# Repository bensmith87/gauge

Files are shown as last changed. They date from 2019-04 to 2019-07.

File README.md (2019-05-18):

<div>Icons made by <a href="https://www.freepik.com/" title="Freepik">Freepik</a> from <a href="https://www.flaticon.com/" 			    title="Flaticon">www.flaticon.com</a> is licensed by <a href="http://creativecommons.org/licenses/by/3.0/" 			    title="Creative Commons BY 3.0" target="_blank">CC 3.0 BY</a></div>

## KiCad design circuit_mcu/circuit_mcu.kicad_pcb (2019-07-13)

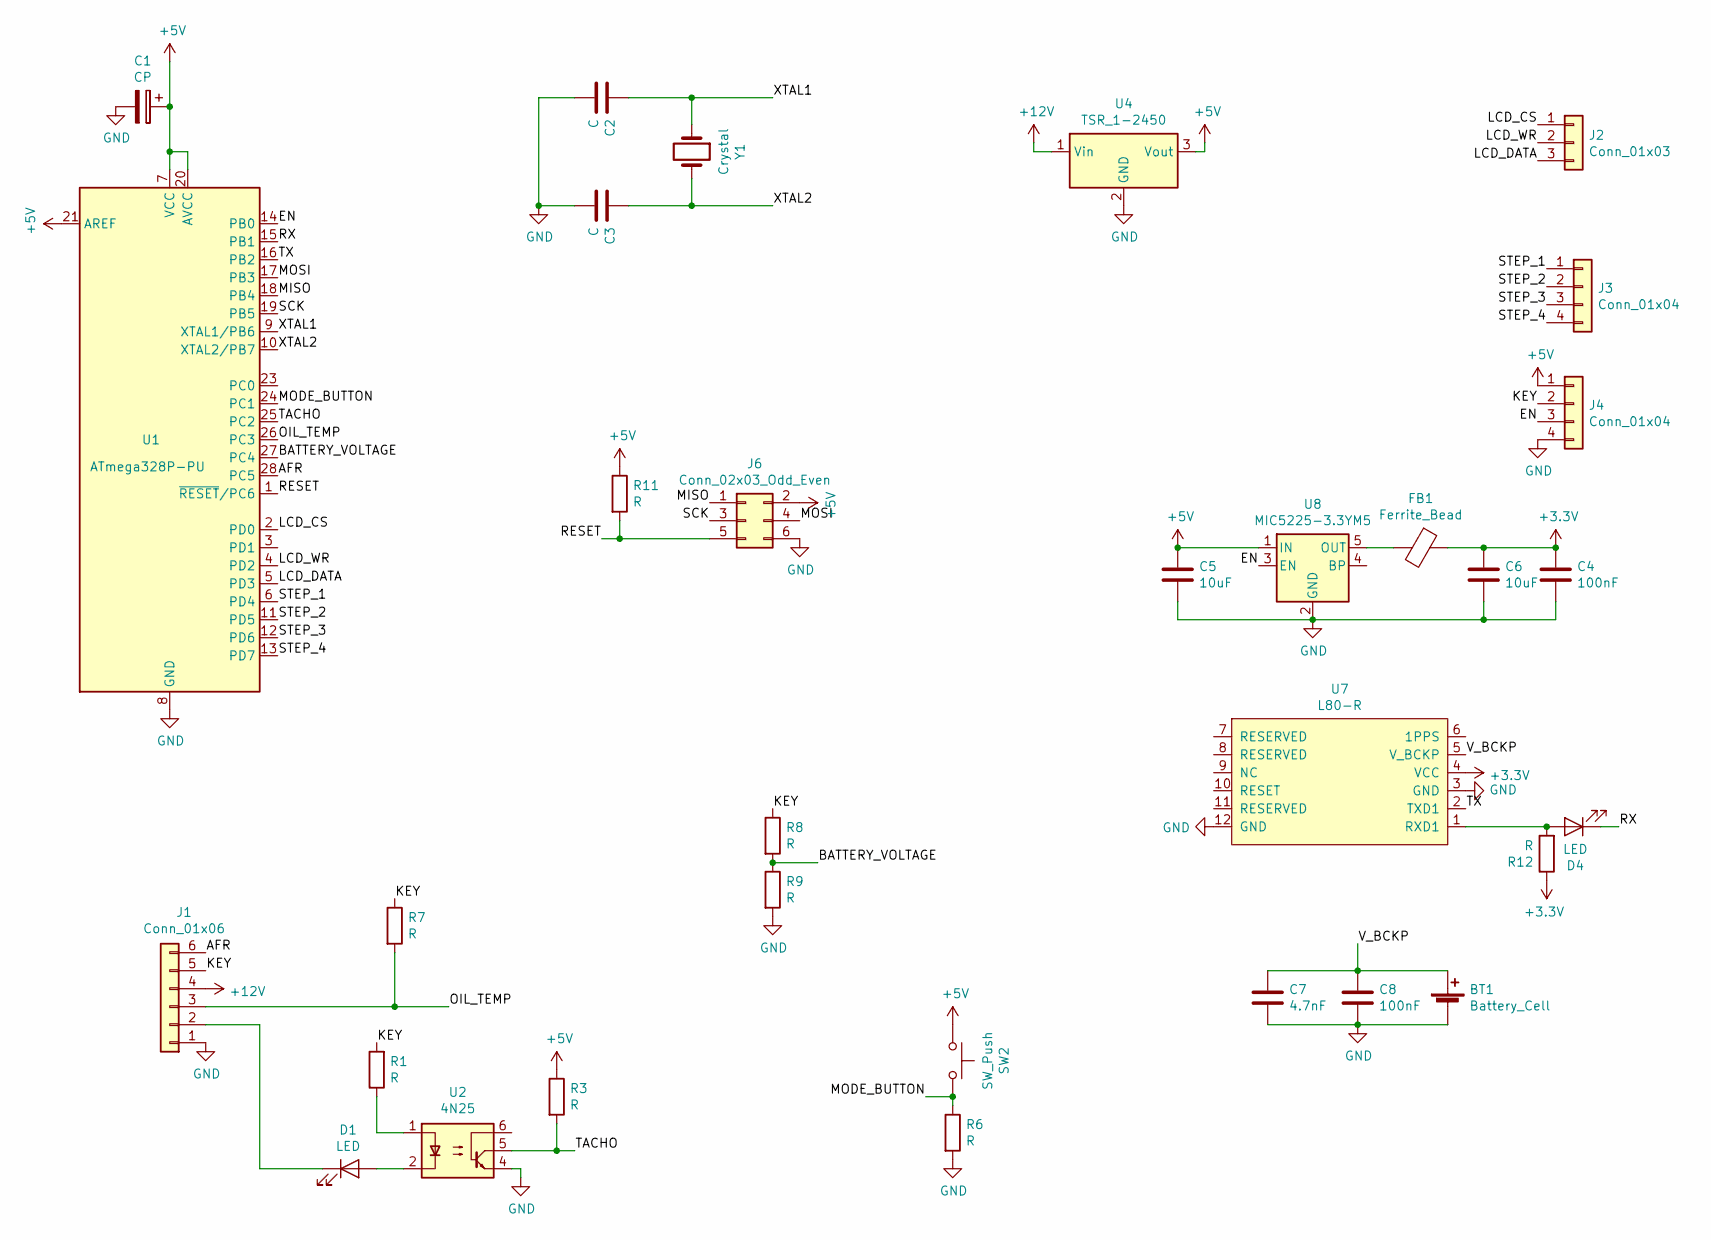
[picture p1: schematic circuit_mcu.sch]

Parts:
BT1: Battery_Cell; Coin Battery Holder
C1: CP; CP_Radial_D4.0mm_P1.50mm
C2, C3: C; C_1206_3216Metric
C4, C8: 100nF; C_1206_3216Metric
C5, C6: 10uF; C_1206_3216Metric
C7: 4.7nF; C_1206_3216Metric
D1, D4: LED; LED_1206_3216Metric
FB1: Ferrite_Bead; L_1206_3216Metric
J1: Conn_01x06; PinSocket_1x06_P2.54mm_Vertical
J2: Conn_01x03; PinSocket_1x03_P2.54mm_Vertical
J3, J4: Conn_01x04; PinSocket_1x04_P2.54mm_Vertical
J6: Conn_02x03_Odd_Even; PinHeader_2x03_P2.54mm_Vertical
R1, R3, R6, R7, R8, R9, R11, R12: R; R_1206_3216Metric
SW2: SW_Push; PinSocket_1x02_P2.54mm_Vertical
U1: ATmega328P-PU; DIP-28_W7.62mm
U2: 4N25; DIP-6_W7.62mm
U4: TSR_1-2450; Converter_DCDC_TRACO_TSR-1_THT
U7: L80-R
U8: MIC5225-3.3YM5; SOT-23-5
Y1: Crystal; Resonator-2Pin_W7.0mm_H2.5mm

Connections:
+3V3: C4.2, C6.2, FB1.1, R12.1, U7.4 (VCC)
+5V: C1.1, C5.2, J4.1, J6.2, R3.1, R11.1, SW2.1, U1.7 (VCC), U1.20 (AVCC), U1.21 (AREF), U4.3 (Vout), U8.1 (IN)
+12V: J1.4, U4.1 (Vin)
/AFR: J1.6, U1.28 (PC5)
/BATTERY_VOLTAGE: R8.2, R9.1, U1.27 (PC4)
/EN: J4.3, U1.14 (PB0), U8.3 (EN)
/KEY: J1.5, J4.2, R1.2, R7.1, R8.1
/LCD_CS: J2.1, U1.2 (PD0)
/LCD_DATA: J2.3, U1.5 (PD3)
/LCD_WR: J2.2, U1.4 (PD2)
/MISO: J6.1, U1.18 (PB4)
/MODE_BUTTON: R6.1, SW2.2, U1.24 (PC1)
/MOSI: J6.4, U1.17 (PB3)
/OIL_TEMP: J1.3, R7.2, U1.26 (PC3)
/RESET: J6.5, R11.2, U1.1 (~RESET~/PC6)
/RX: D4.1 (K), U1.15 (PB1)
/SCK: J6.3, U1.19 (PB5)
/STEP_1: J3.1, U1.6 (PD4)
/STEP_2: J3.2, U1.11 (PD5)
/STEP_3: J3.3, U1.12 (PD6)
/STEP_4: J3.4, U1.13 (PD7)
/TACHO: R3.2, U1.25 (PC2), U2.5
/TX: U1.16 (PB2), U7.2 (TXD1)
/V_BCKP: BT1.1 (+), C7.2, C8.2, U7.5 (V_BCKP)
/XTAL1: C2.1, U1.9 (XTAL1/PB6), Y1.1
/XTAL2: C3.1, U1.10 (XTAL2/PB7), Y1.2
GND: BT1.2 (-), C1.2, C2.2, C3.2, C4.1, C5.1, C6.1, C7.1, C8.1, J1.1, J4.4, J6.6, R6.2, R9.2, U1.8 (GND), U1.22 (GND), U2.4, U4.2 (GND), U7.3 (GND), U7.12 (GND), U8.2 (GND)
unnamed: D1.1 (K), J1.2
unnamed: D1.2 (A), U2.2
unnamed: D4.2 (A), R12.2, U7.1 (RXD1)
unnamed: FB1.2, U8.5 (OUT)
unnamed: R1.1, U2.1

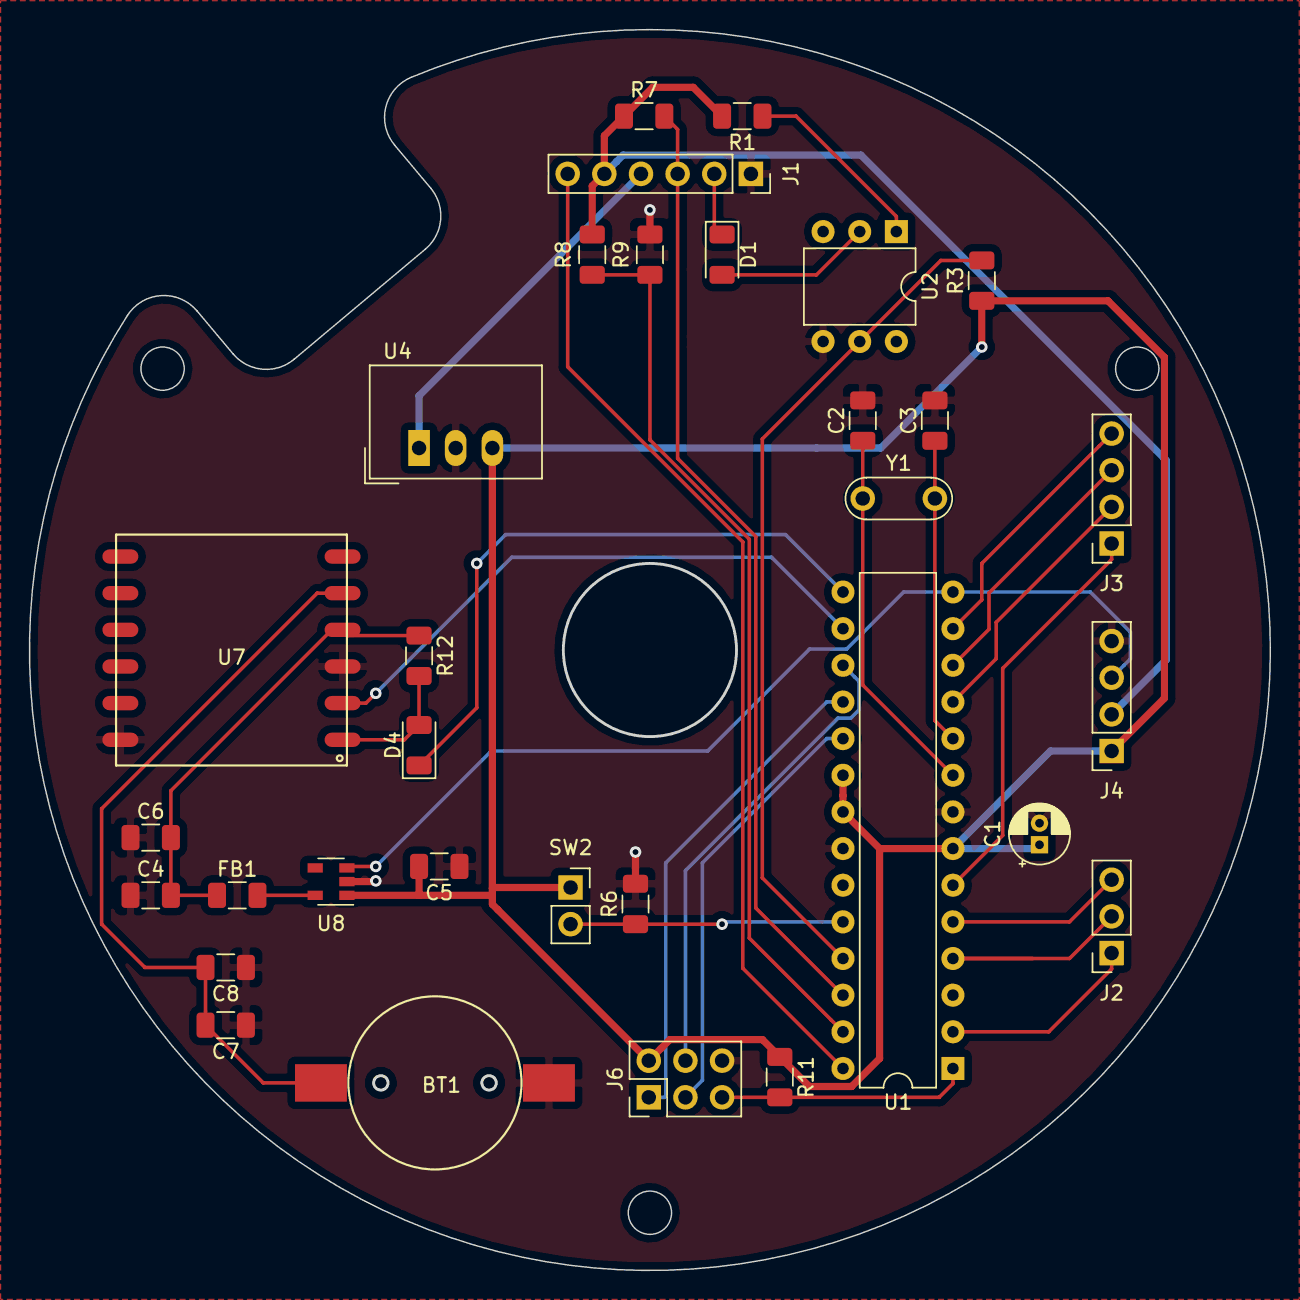
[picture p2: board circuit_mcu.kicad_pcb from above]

Board: 2 copper layers, 86.0 x 86.0 mm, 32 parts (0 on the bottom side), 32 nets.

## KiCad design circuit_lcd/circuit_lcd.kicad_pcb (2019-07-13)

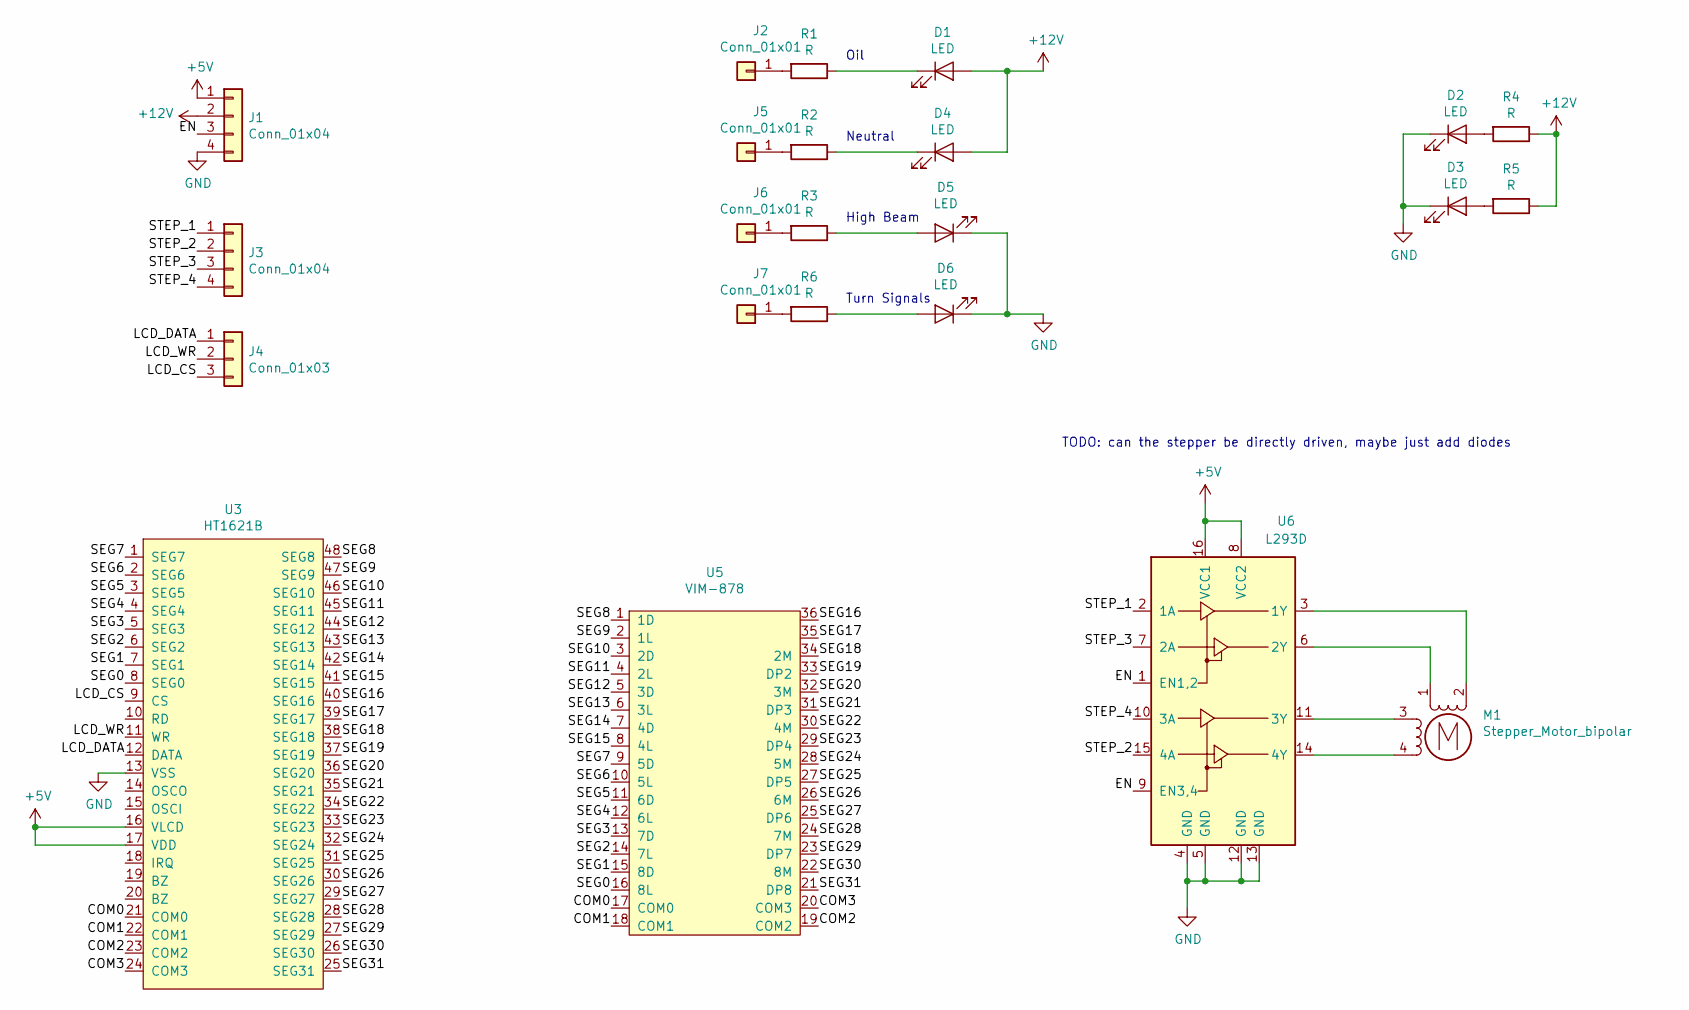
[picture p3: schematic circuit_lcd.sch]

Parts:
D1, D4, D5, D6: LED; LED_D5.0mm
D2, D3: LED; LED_1206_3216Metric
J1, J3: Conn_01x04; PinSocket_1x04_P2.54mm_Vertical
J2, J5, J6, J7: Conn_01x01; PinSocket_1x01_P2.54mm_Vertical
J4: Conn_01x03; PinSocket_1x03_P2.54mm_Vertical
M1: Stepper_Motor_bipolar; Stepper Motor
R1, R2, R3, R4, R5, R6: R; R_1206_3216Metric
U3: HT1621B; HT1621
U5: VIM-878; VIM-878-DP
U6: L293D; DIP-16_W7.62mm

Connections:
+5V: J1.1, U3.16 (VLCD), U3.17 (VDD), U6.8 (VCC2), U6.16 (VCC1)
+12V: D1.2 (A), D4.2 (A), J1.2, R4.1, R5.1
/COM0: U3.21 (COM0), U5.17 (COM0)
/COM1: U3.22 (COM1), U5.18 (COM1)
/COM2: U3.23 (COM2), U5.19 (COM2)
/COM3: U3.24 (COM3), U5.20 (COM3)
/EN: J1.3, U6.1 (EN1,2), U6.9 (EN3,4)
/LCD_CS: J4.3, U3.9 (CS)
/LCD_DATA: J4.1, U3.12 (DATA)
/LCD_WR: J4.2, U3.11 (WR)
/SEG0: U3.8 (SEG0), U5.16 (8L)
/SEG1: U3.7 (SEG1), U5.15 (8D)
/SEG2: U3.6 (SEG2), U5.14 (7L)
/SEG3: U3.5 (SEG3), U5.13 (7D)
/SEG4: U3.4 (SEG4), U5.12 (6L)
/SEG5: U3.3 (SEG5), U5.11 (6D)
/SEG6: U3.2 (SEG6), U5.10 (5L)
/SEG7: U3.1 (SEG7), U5.9 (5D)
/SEG8: U3.48 (SEG8), U5.1 (1D)
/SEG9: U3.47 (SEG9), U5.2 (1L)
/SEG10: U3.46 (SEG10), U5.3 (2D)
/SEG11: U3.45 (SEG11), U5.4 (2L)
/SEG12: U3.44 (SEG12), U5.5 (3D)
/SEG13: U3.43 (SEG13), U5.6 (3L)
/SEG14: U3.42 (SEG14), U5.7 (4D)
/SEG15: U3.41 (SEG15), U5.8 (4L)
/SEG16: U3.40 (SEG16), U5.36
/SEG17: U3.39 (SEG17), U5.35
/SEG18: U3.38 (SEG18), U5.34 (2M)
/SEG19: U3.37 (SEG19), U5.33 (DP2)
/SEG20: U3.36 (SEG20), U5.32 (3M)
/SEG21: U3.35 (SEG21), U5.31 (DP3)
/SEG22: U3.34 (SEG22), U5.30 (4M)
/SEG23: U3.33 (SEG23), U5.29 (DP4)
/SEG24: U3.32 (SEG24), U5.28 (5M)
/SEG25: U3.31 (SEG25), U5.27 (DP5)
/SEG26: U3.30 (SEG26), U5.26 (6M)
/SEG27: U3.29 (SEG27), U5.25 (DP6)
/SEG28: U3.28 (SEG28), U5.24 (7M)
/SEG29: U3.27 (SEG29), U5.23 (DP7)
/SEG30: U3.26 (SEG30), U5.22 (8M)
/SEG31: U3.25 (SEG31), U5.21 (DP8)
/STEP_1: J3.1, U6.2 (1A)
/STEP_2: J3.2, U6.15 (4A)
/STEP_3: J3.3, U6.7 (2A)
/STEP_4: J3.4, U6.10 (3A)
GND: D2.1 (K), D3.1 (K), D5.1 (K), D6.1 (K), J1.4, U3.13 (VSS), U6.4 (GND), U6.5 (GND), U6.12 (GND), U6.13 (GND)
unnamed: D1.1 (K), R1.1
unnamed: D2.2 (A), R4.2
unnamed: D3.2 (A), R5.2
unnamed: D4.1 (K), R2.1
unnamed: D5.2 (A), R3.1
unnamed: D6.2 (A), R6.1
unnamed: J2.1, R1.2
unnamed: J5.1, R2.2
unnamed: J6.1, R3.2
unnamed: J7.1, R6.2
unnamed: M1.1, U6.6 (2Y)
unnamed: M1.2 (-), U6.3 (1Y)
unnamed: M1.3, U6.11 (3Y)
unnamed: M1.4, U6.14 (4Y)

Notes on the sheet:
TODO: can the stepper be directly driven, maybe just add diodes
Oil
Neutral
High Beam
Turn Signals

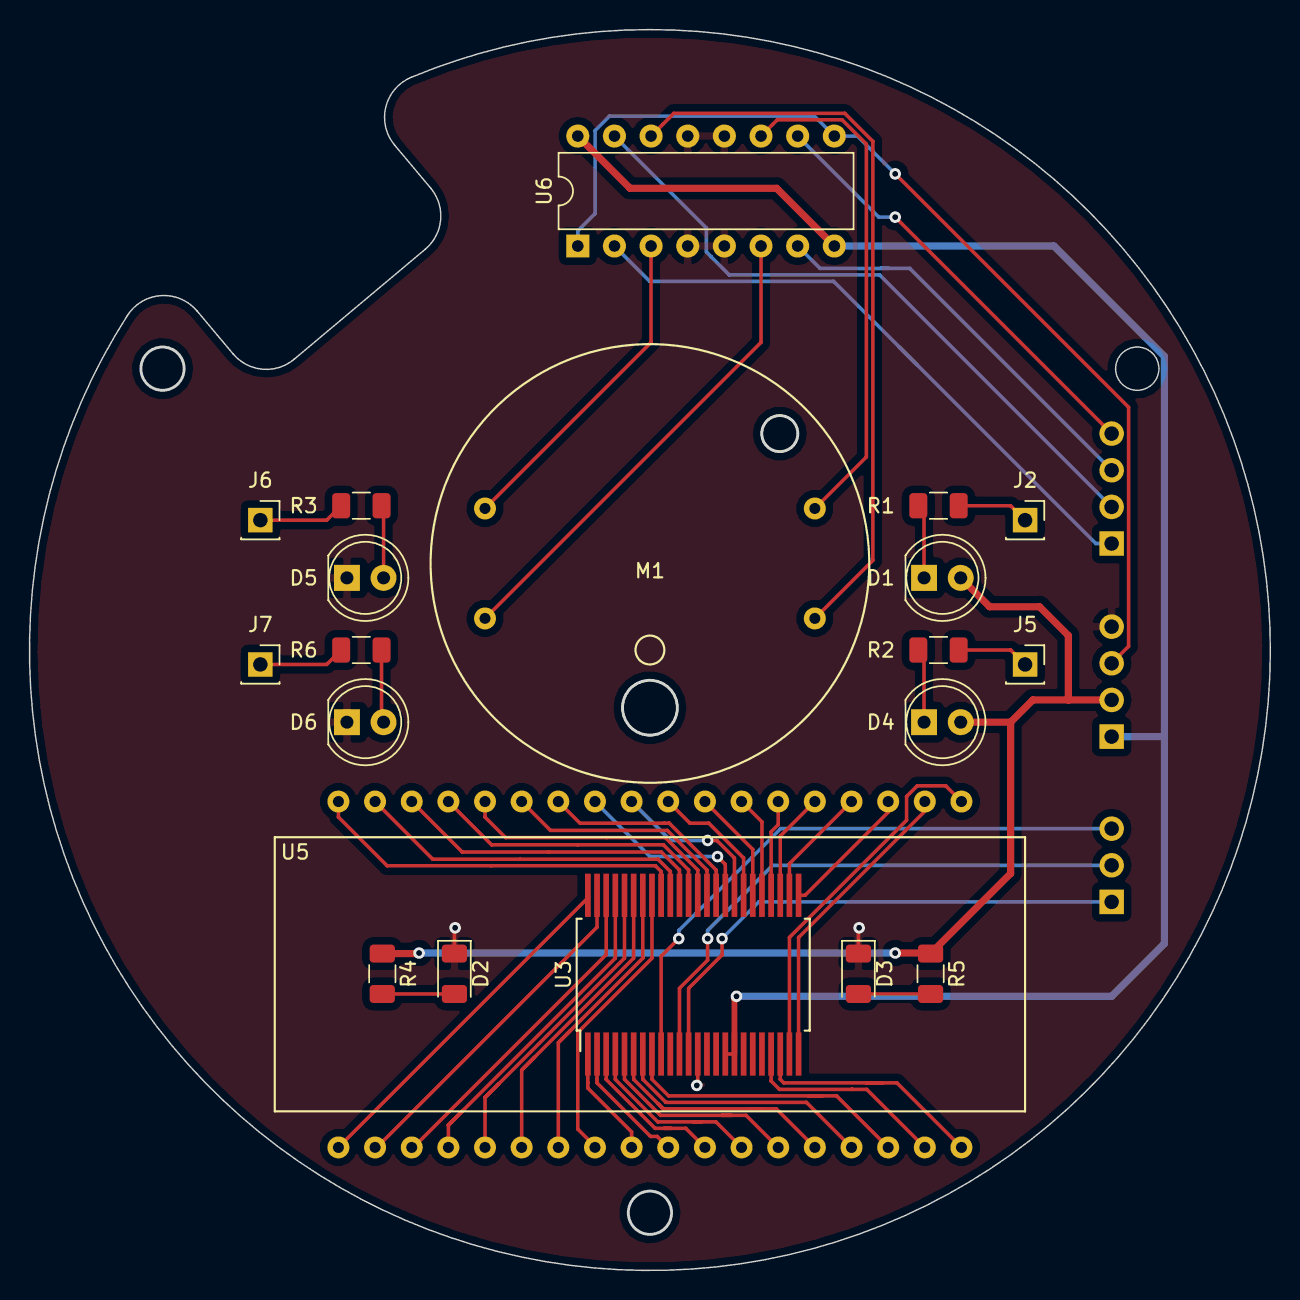
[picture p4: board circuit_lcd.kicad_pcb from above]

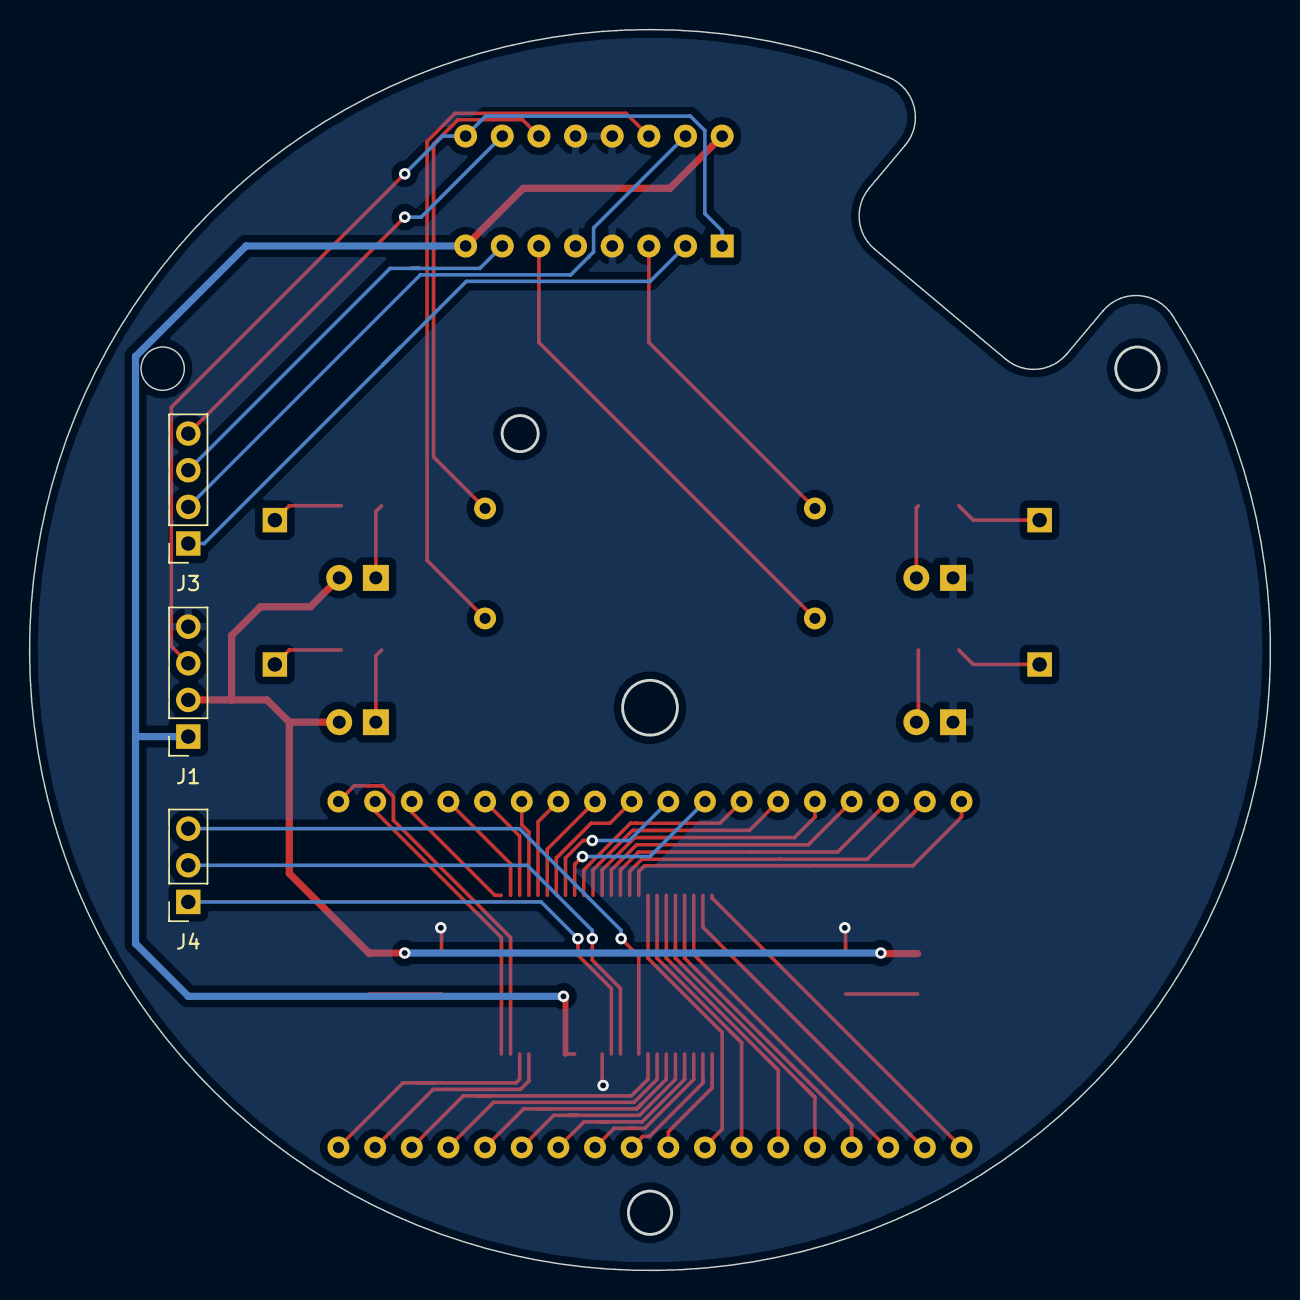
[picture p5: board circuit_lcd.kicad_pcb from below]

Board: 2 copper layers, 86.0 x 86.0 mm, 23 parts (3 on the bottom side), 61 nets.

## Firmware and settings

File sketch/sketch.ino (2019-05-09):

#include "Button.h"
#include "Display.h"
#include "Mode.h"
#include "Speedo.h"
#include "Trip.h"
#include "Odo.h"
#include "Clock.h"
#include "Gps.h"
#include "Tacho.h"
#include "Battery.h"
#include "Afr.h"
#include "OilTemp.h"
#include "Settings.h"

Settings settings = Settings();
Display display = Display();
Button button = Button();
Gps gps = Gps(&settings);
Tacho tacho = Tacho();

Speedo speedo = Speedo(&gps);
Trip trip = Trip(&gps);
Odo odo = Odo(&gps);
Clock clock = Clock(&settings, &gps);
Battery battery = Battery();
Afr afr = Afr();
OilTemp oilTemp = OilTemp();
Mode* modes[] = {
  &speedo,
  &trip,
  &odo,
  &clock,
  &battery,
  &afr,
  &oilTemp
};
int numberOfModes = sizeof(modes) / sizeof(Mode*);
int currentMode = 0;

void setup() {
  Serial.begin(9600);
  
  display.setup();
  settings.setup();
  button.setup();
  gps.setup();
  tacho.setup();

  for (int i = 0; i < numberOfModes; i++) {
    modes[i]->setup();
  }
  
  modes[currentMode]->start();
}

void loop() {
  settings.update();
  button.update();
  tacho.update();
  gps.update();

  for (int i = 0; i < numberOfModes; i++) {
    modes[i]->update();
  }

  if (button.isPressed()) {
    boolean pressConsumed = modes[currentMode]->handlePress(button.isLongPress());
    
    if (button.isShortPress() && !pressConsumed) {
      if (modes[currentMode]->isTitleDisplayed()) {
        currentMode = (currentMode + 1) % numberOfModes;
      }
      modes[currentMode]->start();
    }
  }

  modes[currentMode]->display(&display);
}

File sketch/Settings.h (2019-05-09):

#ifndef SETTINGS_H
#define SETTINGS_H

//#include <SD.h>

#define WRITE_PERIOD 10000
#define TRIP "trip="
#define ODO "odo="
#define HOUR_OFFSET "hourOffset="
#define MINUTE_OFFSET "minuteOffset="

enum TempUnit {
  DEGREES_CELCIUS,
  DEGREES_FAHRENHEIT
};

enum DistanceUnit {
  KILOMETERS,
  MILES
};

enum SpeedUnit {
  KILOMETERS_PER_HOUR,
  MILES_PER_HOUR
};

class Settings {
  long lastWriteTime = -1;
  
public:
  double trip = 0.0;
  double odo = 0.0;
  int hourOffset = 10;
  int minuteOffset = 0;
//  int tempUnits;

  void setup() {
//    Serial.println("Setup Settings...");
//    
//    if (!SD.begin(4)) {
//      Serial.println("SD card setup failed!");
//      while (1);
//    }
//
//    read();
//
//    Serial.println("Done");
  }

  void update() {
//    long time = millis();
//    if (time - lastWriteTime > WRITE_PERIOD) {
//      backup();
//      write();
//      lastWriteTime = time;
//    }
  }
  
private:
//  void read() {
//    File file = SD.open("settings.txt");
//    if (file) {
//      while (file.available()) {
//        String line = file.readStringUntil('\n');
//        Serial.println(line);
//        if (line.startsWith(TRIP)) {
//          trip = line.substring(sizeof(TRIP) - 1).toDouble();
//        } else if (line.startsWith(ODO)) {
//          odo = line.substring(sizeof(ODO) - 1).toDouble();
//        } else if (line.startsWith(HOUR_OFFSET)) {
//          hourOffset = line.substring(sizeof(HOUR_OFFSET) - 1).toInt();
//        } else if (line.startsWith(MINUTE_OFFSET)) {
//          minuteOffset = line.substring(sizeof(MINUTE_OFFSET) - 1).toInt();
//        }
//      }
//      file.close();
//    }
//  }
//
//  void backup() {
//    Serial.print("Backing up Settings...");
//    
//    // TODO: this should back not delete
//    SD.remove("settings.txt");
//    
//    Serial.println("Done");
//  }
//    
//  void write() {
//    File file = SD.open("settings.txt", FILE_WRITE);
//    if (file) {
//      Serial.println("Writing Settings...");
//
//      char line[50];
//      
//      sprintf(line, "%s%f", TRIP, trip);
//      Serial.println(line);
//      file.println(line);
//      
//      sprintf(line, "%s%f", ODO, odo);
//      Serial.println(line);
//      file.println(line);
//      
//      sprintf(line, "%s%d", HOUR_OFFSET, hourOffset);
//      Serial.println(line);
//      file.println(line);
//      
//      sprintf(line, "%s%d", MINUTE_OFFSET, minuteOffset);
//      Serial.println(line);
//      file.println(line);
//      
//      file.close();
//      
//      Serial.println("Done");
//    } else {
//      // if the file didn't open, print an error:
//      Serial.println("Write failed!");
//    }
//  }
};

#endif

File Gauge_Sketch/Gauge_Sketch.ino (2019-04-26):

#include "Button.h"
#include "Mode.h"
#include "Speedo.h"
#include "Trip.h"
#include "Odo.h"
#include "Clock.h"
#include "Gps.h"
#include "Tacho.h"

Display display = Display();
Button button = Button();
Gps gps = Gps();

Tacho tacho = Tacho();

Speedo speedo = Speedo(&gps);
Trip trip = Trip(&gps);
Odo odo = Odo(&gps);
Clock clock = Clock(&gps);
Mode* modes[] = {
  &speedo,
  &trip,
  &odo,
  &clock
};
int numberOfModes = 4;
int currentMode = 0;

bool showTitle = false;

void setup() {
  display.setup();
  button.setup();
  gps.setup();
  tacho.setup();
  
  modes[currentMode]->start();
}

void loop() {
  button.update();

  tacho.update();
  
  if(!gps.update()) {
    Serial.println("FAILED GPS");
    return;
  }

  if (button.isShortPress()) {
    currentMode = (currentMode + 1) % numberOfModes;
    modes[currentMode]->start();
  }    

  for (int i = 0; i < numberOfModes; i++) {
    boolean longPress = i == currentMode ? button.isLongPress() : false;
    modes[i]->update(longPress);
  }

  modes[currentMode]->display(&display);
}

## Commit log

2019-04-26 Added fusion 360 model
    [Gauge.f3d]
2019-04-26 Tacho stepper acceleration
2019-05-09 v1 and v2
    [Gauge.f3d, _saved_circuit.sch, circuit.kicad_pcb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]
2019-07-04 LCD version only
    [Gauge.f3d, circuit.kicad_pcb, circuit.sch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]
2019-07-13 Removed contrast pot and renamed segment nets
    [circuit_lcd.kicad_pcb, circuit_lcd.sch]
2019-07-13 Fixed LCD footprint
    [circuit_lcd.kicad_pcb]
2019-07-13 Added missing segments
    [circuit_lcd.kicad_pcb, circuit_lcd.sch]
2019-07-13 Removed unused LCD read net
    [circuit_lcd.kicad_pcb, circuit_lcd.sch, circuit_mcu.kicad_pcb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]
